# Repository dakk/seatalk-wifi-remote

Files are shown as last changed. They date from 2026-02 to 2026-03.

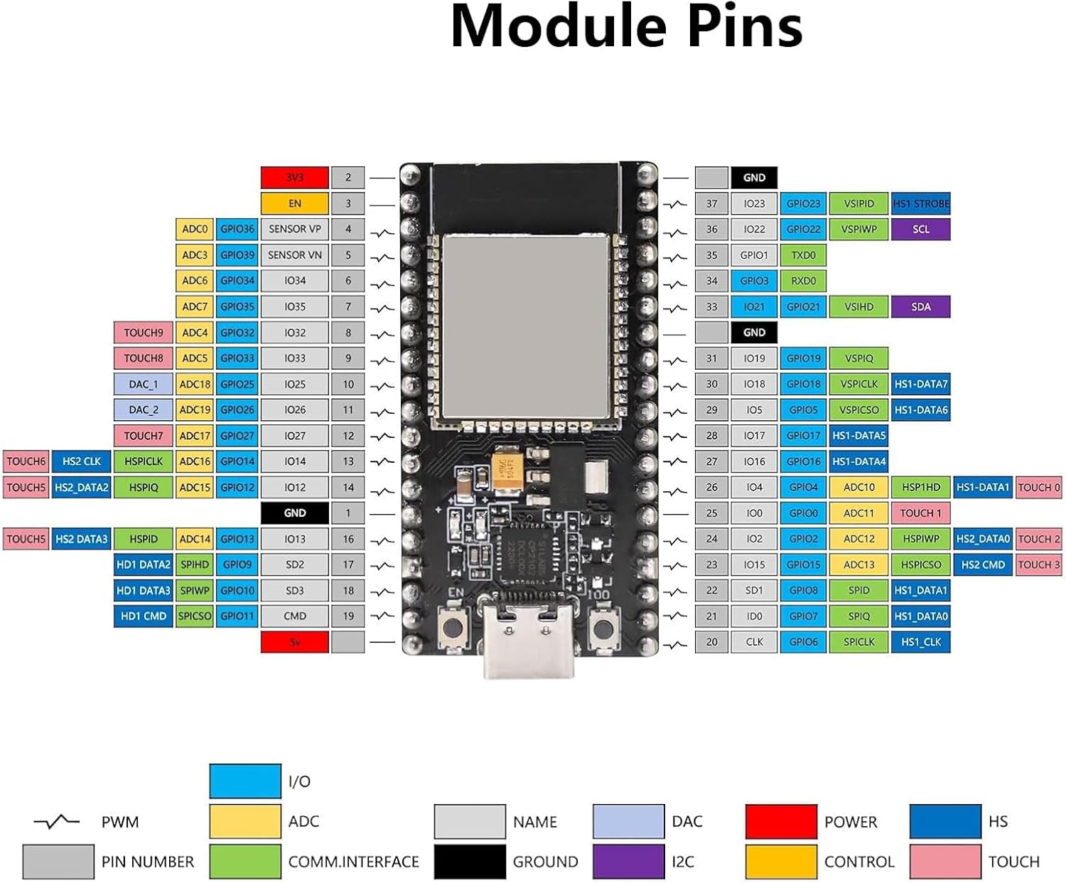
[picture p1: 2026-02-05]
media/esp32pinout.jpg

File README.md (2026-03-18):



# SeaTalk WiFi Remote

An ESP32-based wireless remote controller for marine autopilot systems using the SeaTalk protocol. Control your autopilot remotely over WiFi instead of using hardwired physical buttons.

## Features

- **6 programmable buttons** for autopilot control
- **WiFi UDP communication** to SeaTalk gateway
- **Deep sleep mode** for battery conservation
- **Auto-wake** on button press
- **LED status indicator** with visual feedback patterns
- **3D printable enclosure** (OpenSCAD parametric design)

## Button Functions

| Button | GPIO | Function |
|---|---|---|
| BTN1 | 32 | -1° heading |
| BTN2 | 33 | +1° heading |
| BTN3 | 25 | -10° heading |
| BTN4 | 26 | +10° heading |
| BTN5 | 27 | Auto/Standby toggle |
| BTN6 | 14 | Track mode |

## Hardware Requirements

- ESP32 development board
- 6x tactile push buttons
- LED + resistor (optional, GPIO 2)
- LiPo battery for portable operation
- USB-C charging circuit
- WiFi-to-SeaTalk gateway on your network

## Wiring

All buttons use internal pull-up resistors. Connect buttons between GPIO and GND.

```
ESP32 GPIO 32 ----[BTN1]---- GND
ESP32 GPIO 33 ----[BTN2]---- GND
ESP32 GPIO 25 ----[BTN3]---- GND
ESP32 GPIO 26 ----[BTN4]---- GND
ESP32 GPIO 27 ----[BTN5]---- GND
ESP32 GPIO 14 ----[BTN6]---- GND
ESP32 GPIO 2  ----[LED]--[R]---- GND
```

## Configuration

1. Copy the example configuration file:

```bash
cp seatalk-wifi-remote/conf_example.h seatalk-wifi-remote/conf.h
```

2. Edit `seatalk-wifi-remote/conf.h` with your WiFi credentials and gateway settings:

```cpp
#define WIFI_SSID "MyBoatWiFi"
#define WIFI_PASSWORD "my_secret_password"

#define SEATALK_GATEWAY_IP "192.168.1.100"  // SeaTalk gateway IP
#define SEATALK_GATEWAY_PORT 4001           // SeaTalk gateway port
```

> **Note:** `conf.h` is gitignored to prevent committing your credentials.

## Building

### Prerequisites

- [Arduino CLI](https://arduino.github.io/arduino-cli/)
- ESP32 Arduino core

### Install ESP32 Core

```bash
cd seatalk-wifi-remote
make install-core
```

### Build and Upload

```bash
make build          # Compile only
make upload         # Build and upload
make monitor        # Open serial monitor
make upload-monitor # Upload and open monitor
```

## Power Management

- **Enter sleep**: Hold BTN1 + BTN6 for 2 seconds
- **Wake up**: Press any button
- **Auto-sleep**: After 1 minute of inactivity (configurable)

### LED Patterns

| Pattern | Meaning |
|---|---|
| 3 blinks | Startup complete |
| Single flash | Command sent |
| 10 rapid blinks | WiFi connection error |
| 5 blinks | Entering sleep mode |

## 3D Printed Enclosure

Multiple enclosure versions are available in the `enclosure/` directory:

### Version 3 (Recommended)

Located in `enclosure/v3/` - waterproof custom design with TPU button mask and back gasket.

**Dimensions:** 82mm × 102mm × 35mm (external)

```bash
cd enclosure/v3
make           # Generate all STL files
```

### Version 2

Located in `enclosure/v2/` - YAPP-based design with 20mm internal clearance for ESP32 and battery.

**Dimensions:** 78mm × 98mm × 35mm (external)

```bash
cd enclosure/v2
make           # Generate all STL files
```

### Version 1 (Compact)

Located in `enclosure/v1-mini/` - compact nke-style remote design.

**Dimensions:** 78mm × 58mm × 23mm (external)

## SeaTalk Protocol

The remote sends SeaTalk Datagram 86 (Autopilot Remote Keystroke) commands:

| Key Code | Command |
|---|---|
| 0x05 | -1° |
| 0x06 | +1° |
| 0x07 | -10° |
| 0x08 | +10° |
| 0x01 | Auto |
| 0x02 | Standby |
| 0x03 | Track |

## License

MIT License

## Acknowledgments

- [YAPP Box Generator](https://github.com/mrWheel/YAPP_Box) for parametric enclosure design
- SeaTalk protocol documentation from the marine open-source community

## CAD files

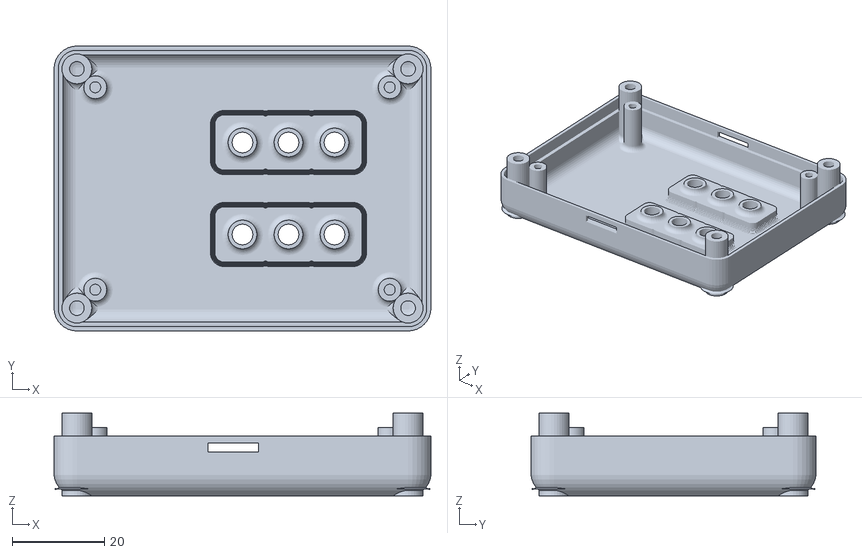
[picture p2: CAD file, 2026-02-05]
enclosure/v1-mini/auto_top.stl
82.0 x 62.0 x 18.0

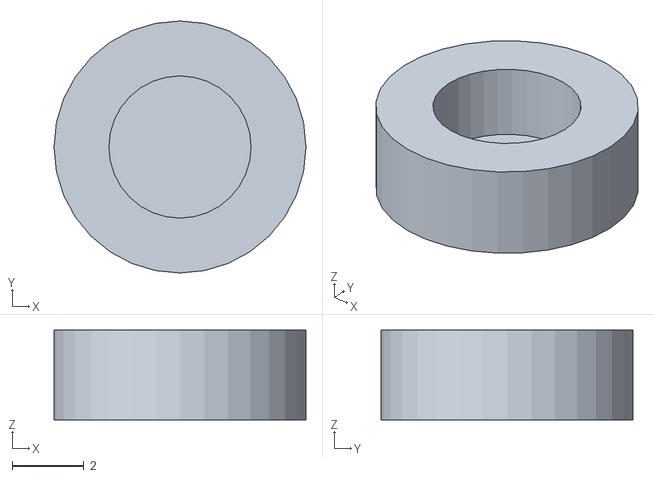
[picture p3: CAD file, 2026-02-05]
enclosure/v1-mini/auto_button_b.stl
7.00 x 7.00 x 2.50

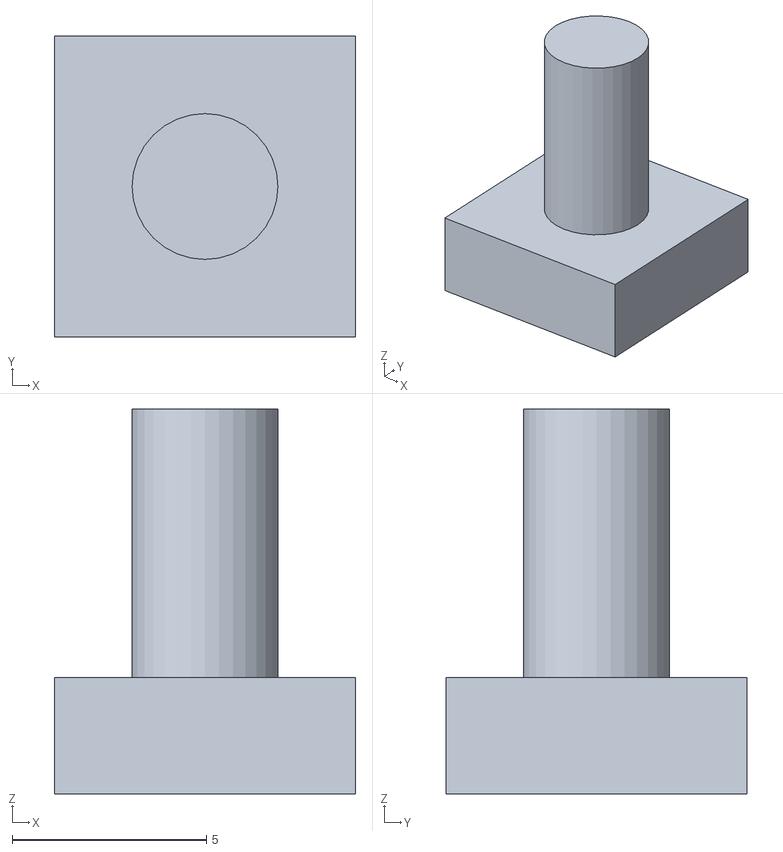
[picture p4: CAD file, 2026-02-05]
enclosure/v1-mini/auto_button_a.stl
7.75 x 7.75 x 9.90

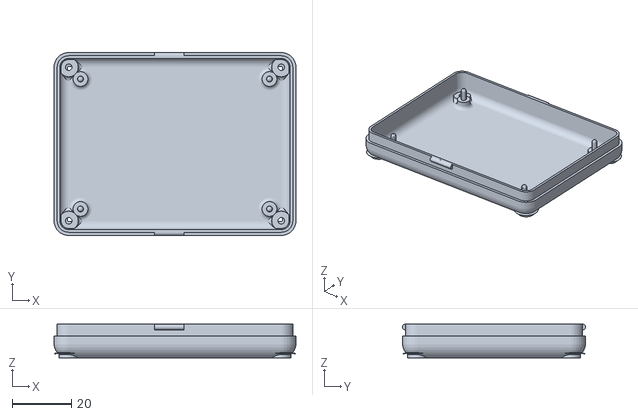
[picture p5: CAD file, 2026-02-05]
enclosure/v1-mini/auto_bottom.stl
82.0 x 62.0 x 11.5

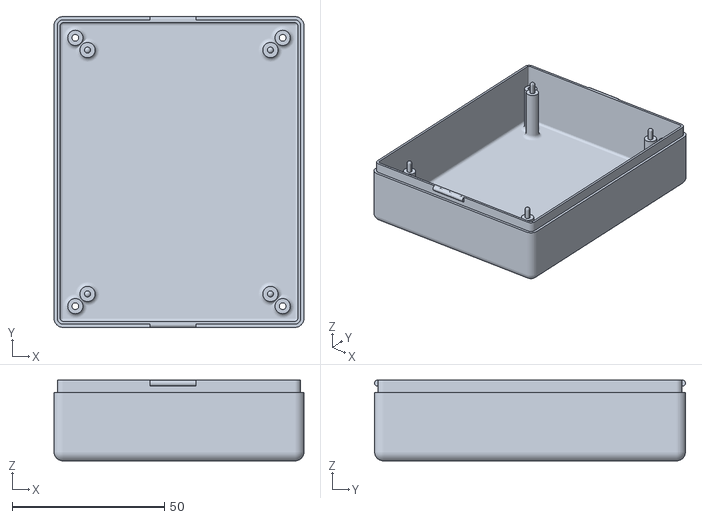
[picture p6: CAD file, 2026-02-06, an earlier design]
enclosure/v2/stl/base.stl
82.0 x 102.0 x 26.5

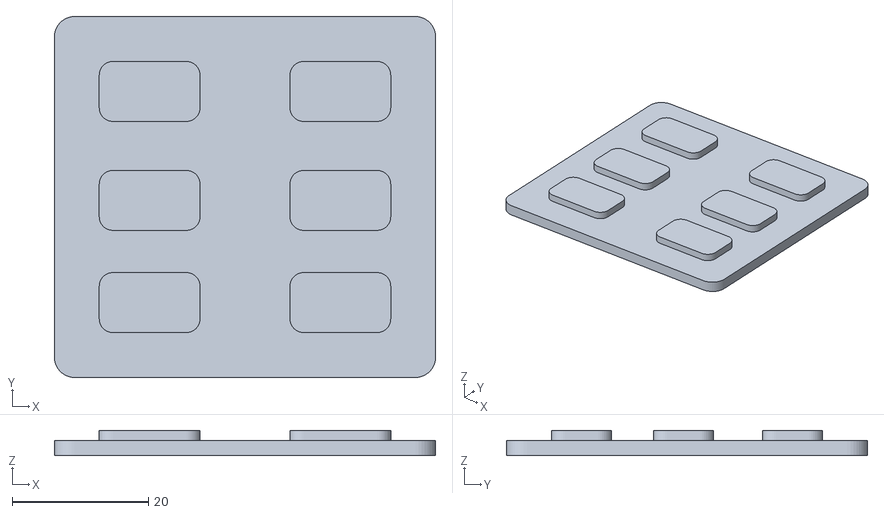
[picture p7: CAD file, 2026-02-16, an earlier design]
enclosure/v3/stl/tpu_mask.stl
56.0 x 53.0 x 3.70

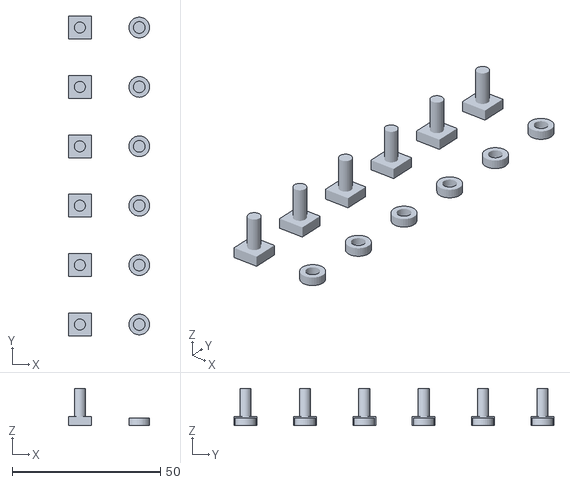
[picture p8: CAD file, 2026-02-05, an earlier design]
enclosure/v2/stl/extenders.stl
27.4 x 107.8 x 12.5

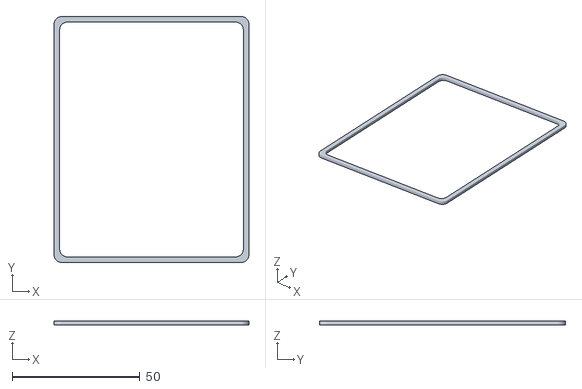
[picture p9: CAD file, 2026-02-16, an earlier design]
enclosure/v3/stl/back_gasket.stl
76.2 x 96.2 x 1.40

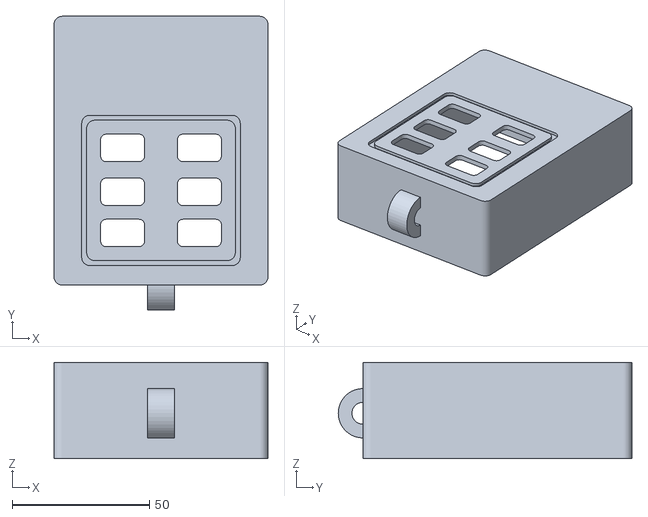
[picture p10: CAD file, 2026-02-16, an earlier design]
enclosure/v3/stl/enclosure.stl
78.0 x 107.0 x 35.0

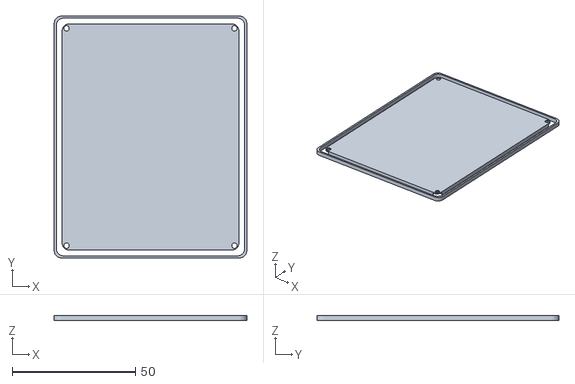
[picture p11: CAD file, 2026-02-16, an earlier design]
enclosure/v3/stl/back_cover.stl
78.0 x 98.0 x 2.00

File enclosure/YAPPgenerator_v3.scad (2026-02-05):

/*
***************************************************************************  
**  Yet Another Parameterised Projectbox generator
**
*/

Version="v3.1.2 (2024-04-12)";

/*
**
**  Copyright (c) 2021, 2022, 2023, 2024 Willem Aandewiel
**
**  With help from:
**   - Keith Hadley (parameterized label depth)
**   - Oliver Grafe (connectorsPCB)
**   - Juan Jose Chong (dynamic standoff flange)
**   - Dan Drum (cleanup code)
**   - Dave Rosenhauer (fillets and a lot more)
**
**
**  for many or complex cutouts you might need to adjust
**  the number of elements:
**
**      Preferences->Advanced->Turn off rendering at 250000 elements
**                                                  ^^^^^^
**
**  TERMS OF USE: MIT License. See base offile.
***************************************************************************      
*/

// If set to true will generate the sample box at every save
debug = false;
printMessages = debug;

//---------------------------------------------------------
// This design is parameterized based on the size of a PCB.
//---------------------------------------------------------
// Note: length/lengte refers to X axis, 
//       width/breedte to Y, 
//       height/hoogte to Z

/*
      padding-back|<------pcb length --->|<padding-front
                            RIGHT
        0    X-axis ---> 
        +----------------------------------------+   ---
        |                                        |    ^
        |                                        |   padding-right 
      Y |                                        |    v
      | |    -5,y +----------------------+       |   ---              
 B    a |         | 0,y              x,y |       |     ^              F
 A    x |         |                      |       |     |              R
 C    i |         |                      |       |     | pcb width    O
 K    s |         |                      |       |     |              N
        |         | 0,0              x,0 |       |     v              T
      ^ |    -5,0 +----------------------+       |   ---
      | |                                        |    padding-left
      0 +----------------------------------------+   ---
        0    X-as --->
                          LEFT
*/

//-- which part(s) do you want to print?
printBaseShell        = true;
printLidShell         = true;
printSwitchExtenders  = true;
printDisplayClips     = true;
shiftLid              = 10;  // Set the distance between the lid and base when rendered or previewed side by side
                            
//-- padding between pcb and inside wall
paddingFront        = 1;
paddingBack         = 1;
paddingRight        = 1;
paddingLeft         = 1;

// ********************************************************************
// The Following will be used as the first element in the pbc array

//Defined here so you can define the "Main" PCB using these if wanted
pcbLength           = 120; // front to back (X axis)
pcbWidth            = 50; // side to side (Y axis)
pcbThickness        = 1.6;
standoffHeight      = 1.0;  //-- How much the PCB needs to be raised from the base to leave room for solderings 
standoffDiameter    = 7;
standoffPinDiameter = 2.4;
standoffHoleSlack   = 0.4;

//===================================================================
// *** PCBs ***
// Printed Circuit Boards
//-------------------------------------------------------------------
//  Default origin =  yappCoordPCB : yappCoordBoxInside[0,0,0]
//
//  Parameters:
//   Required:
//    p(0) = name
//    p(1) = length
//    p(2) = width
//    p(3) = posx
//    p(4) = posy
//    p(5) = Thickness
//    p(6) = standoff_Height
//    p(7) = standoff_Diameter
//    p(8) = standoff_PinDiameter
//   Optional:
//    p(9) = standoff_HoleSlack (default to 0.4)

//The following can be used to get PCB values. If "PCB Name" is omitted then "Main" is used
//  pcbLength           --> pcbLength("PCB Name")
//  pcbWidth            --> pcbWidth("PCB Name")
//  pcbThickness        --> pcbThickness("PCB Name") 
//  standoffHeight      --> standoffHeight("PCB Name") 
//  standoffDiameter    --> standoffDiameter("PCB Name") 
//  standoffPinDiameter --> standoffPinDiameter("PCB Name") 
//  standoffHoleSlack   --> standoffHoleSlack("PCB Name") 

pcb = 
[
  //-- Default Main PCB - DO NOT REMOVE the "Main" line.
  ["Main",              pcbLength,pcbWidth,    0,0,    pcbThickness,  standoffHeight, standoffDiameter, standoffPinDiameter, standoffHoleSlack]
];

//-------------------------------------------------------------------

//-- Edit these parameters for your own box dimensions
wallThickness       = 2.0;
basePlaneThickness  = 1.5;
lidPlaneThickness   = 1.5;

//-- Total height of box = lidPlaneThickness 
//                       + lidWallHeight 
//                       + baseWallHeight 
//                       + basePlaneThickness
//-- space between pcb and lidPlane :=
//--      (bottonWallHeight+lidWallHeight) - (standoff_Height+pcb_Thickness)
baseWallHeight      = 10;
lidWallHeight       = 10;

//-- ridge where base and lid off box can overlap
//-- Make sure this isn't less than lidWallHeight 
//     or 1.8x wallThickness if using snaps
ridgeHeight         = 5.0;
ridgeSlack          = 0.3;

//-- Radius of the shell corners
roundRadius         = wallThickness + 1;

//---------------------------
//--     MISC Options     --
//---------------------------

//-- Cone aperture in degrees for countersunk-head screws
countersinkAngle = 90;          //-- metric: 90

// Set the layer height of your printer
printerLayerHeight  = 0.2;

// Set the ratio between the wall thickness and the ridge height. 
//    Recommended to be left at 1.8 but for strong snaps.
wallToRidgeRatio = 1.8;

//---------------------------
//--     C O N T R O L     --
//---------------------------
// -- Render --
renderQuality             = 8;          //-> from 1 to 32, Default = 8

// --Preview --
previewQuality            = 5;          //-> from 1 to 32, Default = 5
showSideBySide            = true;       //-> Default = true
onLidGap                  = 0;  // tip don't override to animate the lid opening
//onLidGap                  = ((ridgeHeight) - (ridgeHeight * abs(($t-0.5)*2)))*2;  // tip don't override to animate the lid opening/closing
colorLid                  = "YellowGreen";   
alphaLid                  = 1;
colorBase                 = "BurlyWood";
alphaBase                 = 1;
hideLidWalls              = false;      //-> Remove the walls from the lid : only if preview and showSideBySide=true 
hideBaseWalls             = false;      //-> Remove the walls from the base : only if preview and showSideBySide=true  
showOrientation           = true;       //-> Show the Front/Back/Left/Right labels : only in preview
showPCB                   = false;      //-> Show the PCB in red : only in preview 
showSwitches              = false;      //-> Show the switches (for pushbuttons) : only in preview 
showButtonsDepressed      = false;      //-> Should the buttons in the Lid On view be in the pressed position
showOriginCoordBox        = false;      //-> Shows red bars representing the origin for yappCoordBox : only in preview 
showOriginCoordBoxInside  = false;      //-> Shows blue bars representing the origin for yappCoordBoxInside : only in preview 
showOriginCoordPCB        = false;      //-> Shows blue bars representing the origin for yappCoordBoxInside : only in preview 
showMarkersPCB            = false;      //-> Shows black bars corners of the PCB : only in preview 
showMarkersCenter         = false;      //-> Shows magenta bars along the centers of all faces  
inspectX                  = 0;          //-> 0=none (>0 from Back)
inspectY                  = 0;          //-> 0=none (>0 from Right)
inspectZ                  = 0;          //-> 0=none (>0 from Bottom)
inspectXfromBack          = true;       //-> View from the inspection cut foreward
inspectYfromLeft          = true;       //-> View from the inspection cut to the right
inspectZfromBottom        = true;       //-> View from the inspection cut up
//---------------------------
//--     C O N T R O L     --
//---------------------------

// ******************************
//  REMOVE BELOW FROM TEMPLATE

// Set the glogal for the quality
facetCount = $preview ? previewQuality*4 : renderQuality*4;

//-- better leave these ----------
buttonWall          = 2.0;
buttonPlateThickness= 2.5;
buttonSlack         = 0.25;

//-- constants, do not change (shifted to large negative values so another element in the 
//-- array won't match

// Define some alternates to undef
yappDefault             = undef;
default                 = undef;

// Shapes
yappRectangle           = -30000;
yappCircle              = -30001;
yappPolygon             = -30002;
yappRoundedRect         = -30003;
yappCircleWithFlats     = -30004;
yappCircleWithKey       = -30005;
yappRing                = -30006;
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

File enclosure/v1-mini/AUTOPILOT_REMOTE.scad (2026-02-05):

//-----------------------------------------------------------------------
// ESP32 Sailing Autopilot Remote - nke style
// Based on YAPP Box Generator v3
//-----------------------------------------------------------------------
include <../Enclosures/YAPP_Box/YAPPgenerator_v3.scad>

//-- which part(s) do you want to print?
printBaseShell        = true;
printLidShell         = true;
printSwitchExtenders  = true;

// PCB dimensions - adjust to your ESP32 board
pcbLength           = 70;    // X axis (front to back)
pcbWidth            = 50;    // Y axis (side to side)
pcbThickness        = 1.6;
standoffHeight      = 3.0;   // space below PCB for soldering/battery
standoffDiameter    = 5;
standoffPinDiameter = 2.0;
standoffHoleSlack   = 0.4;

pcb = 
[
  ["Main", pcbLength, pcbWidth, 0, 0, pcbThickness, standoffHeight, 
   standoffDiameter, standoffPinDiameter, standoffHoleSlack]
];

//-- padding between PCB and inside wall
paddingFront  = 4;
paddingBack   = 4;
paddingRight  = 4;
paddingLeft   = 4;

//-- wall dimensions
wallThickness       = 2.0;
basePlaneThickness  = 1.5;
lidPlaneThickness   = 1.5;

//-- Total height ~23mm (nke remote style)
baseWallHeight  = 10;
lidWallHeight   = 8;

//-- ridge for lid/base overlap (sealing area)
ridgeHeight  = 4.0;
ridgeSlack   = 0.2;
roundRadius  = 5.0;   // rounded corners

boxType = 0;  // all edges rounded

printerLayerHeight = 0.2;

//-- Preview settings
renderQuality    = 8;
previewQuality   = 5;
showSideBySide   = true;
colorLid         = "DarkSlateGray";
colorBase        = "SlateGray";
showPCB          = true;
showSwitches     = true;

//===================================================================
// *** PCB Supports - mounting posts for ESP32 ***
//-------------------------------------------------------------------
pcbStands = 
[
  // 4 corner standoffs (adjust to your ESP32 mounting holes)
  [3,  3,  standoffHeight, -1, standoffDiameter, standoffPinDiameter],
  [3,  pcbWidth-3],
  [pcbLength-3, 3],
  [pcbLength-3, pcbWidth-3]
];

//===================================================================
// *** Cutouts - FIXED FORMAT ***
//-------------------------------------------------------------------
cutoutsLid = 
[
  // 6 button holes: 10mm diameter circles, 2x3 grid centered on lid
  // Format: [x, y, diameter, diameter, yappCircle]
  // Row 1 (top)
  [35, 15, 10, 10, yappCircle],
  [35, 35, 10, 10, yappCircle],
  // Row 2 (middle)  
  [45, 15, 10, 10, yappCircle],
  [45, 35, 10, 10, yappCircle],
  // Row 3 (bottom)
  [55, 15, 10, 10, yappCircle],
  [55, 35, 10, 10, yappCircle]
];

cutoutsBase = [];

// USB-C charging port on front face
cutoutsFront = 
[
  // USB-C: 9mm wide x 3.5mm tall, centered vertically
  [9, 32, 9, 3.5, yappRoundedRect]
];

cutoutsBack   = [];
cutoutsLeft   = [];
cutoutsRight  = [];

//===================================================================
// *** Push Buttons - printed extenders for tactile switches ***
//-------------------------------------------------------------------
pushButtons = 
[
  // Match cutouts exactly - adjust switchHeight to your tact switches
  [35, 15, 8, 8, 2, 1.5, 6.0, 0.5, 4, standoffHeight + pcbThickness],
  [35, 35, 8, 8, 2, 1.5, 6.0, 0.5, 4, standoffHeight + pcbThickness],
  [45, 15, 8, 8, 2, 1.5, 6.0, 0.5, 4, standoffHeight + pcbThickness],
  [45, 35, 8, 8, 2, 1.5, 6.0, 0.5, 4, standoffHeight + pcbThickness],
  [55, 15, 8, 8, 2, 1.5, 6.0, 0.5, 4, standoffHeight + pcbThickness],
  [55, 35, 8, 8, 2, 1.5, 6.0, 0.5, 4, standoffHeight + pcbThickness]
];

//===================================================================
// *** Snap Joins - clips to hold lid and base together ***
//-------------------------------------------------------------------
snapJoins = 
[
  [(pcbLength + paddingFront + paddingBack)/2, 10, yappLeft, yappRight, yappCenter]
];

//===================================================================
// *** Labels - embossed text ***
//-------------------------------------------------------------------
labelsPlane = 
[
  // Example button labels
  // [45, 15+12, 0, 0.4, yappLid, "Liberation Sans:style=Bold", 4, "AUTO"],
  // [45, 35-12, 0, 0.4, yappLid, "Liberation Sans:style=Bold", 4, "STBY"],
  // [35, 25, 0, 0.4, yappLid, "Liberation Sans", 3, "+1"],
  // [55, 25, 0, 0.4, yappLid, "Liberation Sans", 3, "-1"]
];

//===================================================================
// *** Connectors - screw posts for secure closure ***
//-------------------------------------------------------------------
connectors = 
[
  // 4 corner M2 screw posts
  [5, 5, standoffHeight, 2.2, 4.5, 2.2, 4, yappAllCorners, yappCoordBox],
];

boxMounts     = [];
lightTubes    = [];
ridgeExtLeft  = [];
ridgeExtRight = [];
ridgeExtFront = [];
ridgeExtBack  = [];
displayMounts = [];

//---- Generate the box ----
YAPPgenerate();

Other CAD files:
enclosure/v2/AUTOPILOT_REMOTE.scad
enclosure/v3/v3.scad

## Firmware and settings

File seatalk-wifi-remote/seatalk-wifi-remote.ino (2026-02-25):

/*
 * SeaTalk WiFi Remote Controller
 * ESP32-based remote with 6 buttons for autopilot control
 *
 * Features:
 * - WiFi connectivity to SeaTalk gateway
 * - 6 configurable buttons for autopilot commands
 * - Deep sleep mode (BTN1 + BTN6 to enter sleep)
 * - Wake from sleep by pressing BTN1 (Auto)
 */

#include <WiFi.h>
#include <WiFiUdp.h>
#include <esp_sleep.h>
#include <driver/rtc_io.h>

// ============== CONFIGURATION ==============

#include "conf.h"

// Button GPIO pins (choose RTC-capable GPIOs for wake-up support)
// RTC GPIOs on ESP32: 0, 2, 4, 12-15, 25-27, 32-39
#define BTN1_PIN  32  // -1 degree
#define BTN2_PIN  33  // +1 degree
#define BTN3_PIN  25  // -10 degrees
#define BTN4_PIN  26  // +10 degrees
#define BTN5_PIN  27  // Auto/Standby toggle
#define BTN6_PIN  14  // Track mode

// LED indicator (optional)
#define LED_PIN   2

// Button debounce time in milliseconds
#define DEBOUNCE_MS 50

// Sleep mode key combination hold time (milliseconds)
#define SLEEP_COMBO_HOLD_MS 2000

// WiFi connection timeout (milliseconds)
#define WIFI_TIMEOUT_MS 10000

// ============== SEATALK COMMANDS ==============
// SeaTalk autopilot remote keystroke commands (Datagram 86)
// Format: 86 X1 YY - where X1 = key code, YY = 0x00

// Keystroke codes for autopilot
const uint8_t ST_KEY_MINUS_1    = 0x05;  // -1 degree
const uint8_t ST_KEY_PLUS_1     = 0x06;  // +1 degree
const uint8_t ST_KEY_MINUS_10   = 0x07;  // -10 degrees
const uint8_t ST_KEY_PLUS_10    = 0x08;  // +10 degrees
const uint8_t ST_KEY_AUTO       = 0x01;  // Auto mode
const uint8_t ST_KEY_STANDBY    = 0x02;  // Standby mode

// ============== GLOBAL VARIABLES ==============

WiFiUDP udp;

// Button state tracking
struct Button {
  uint8_t pin;
  uint8_t command;
  bool lastState;
  bool currentState;
  unsigned long lastDebounceTime;
  bool pressed;
};

Button buttons[6] = {
  {BTN1_PIN, ST_KEY_AUTO,  true, true, 0, false},
  {BTN2_PIN, ST_KEY_MINUS_10,   true, true, 0, false},
  {BTN3_PIN, ST_KEY_MINUS_1, true, true, 0, false},
  {BTN4_PIN, ST_KEY_PLUS_1,  true, true, 0, false},
  {BTN5_PIN, ST_KEY_PLUS_10,     true, true, 0, false},  // Toggle auto/standby
  {BTN6_PIN, ST_KEY_STANDBY,  true, true, 0, false}
};

unsigned long sleepComboStartTime = 0;
bool sleepComboActive = false;
unsigned long lastActivityTime = 0;  // Track last button activity for auto-sleep
int wifiFailCount = 0;  // Track consecutive WiFi connection failures

// ============== FUNCTION DECLARATIONS ==============

void setupButtons();
void setupWiFi();
void updateButtons();
uint8_t nmeaChecksum(const char* sentence);
void sendSeaTalkCommand(uint8_t keyCode);
void checkSleepCombo();
void enterDeepSleep();
void blinkLED(int times, int delayMs);
void printWakeupReason();

// ============== SETUP ==============

void setup() {
  Serial.begin(115200);
  delay(100);

  Serial.println("\n\n=================================");
  Serial.println("SeaTalk WiFi Remote Controller");
  Serial.println("=================================\n");

  // Print wake-up reason
  printWakeupReason();

  // Initialize LED
  pinMode(LED_PIN, OUTPUT);
  digitalWrite(LED_PIN, LOW);

  // Initialize buttons
  setupButtons();

  #ifdef DEBUG_MODE
    Serial.println("*** DEBUG MODE ENABLED ***");
    Serial.println("WiFi and SeaTalk are disabled.");
    Serial.println("Press any button to test. LED blinks = button number.\n");
    blinkLED(10, 50);
  #else
    // Connect to WiFi
    setupWiFi();
  #endif

  // Indicate ready
  blinkLED(3, 100);

  // Initialize activity timer
  lastActivityTime = millis();

  Serial.println("\nRemote ready!");
  Serial.println("- Press BTN1+BTN6 for 2 seconds to enter sleep mode");
  Serial.printf("- Auto-sleep after %d minutes of inactivity\n", INACTIVITY_TIMEOUT_MIN);
  Serial.println("- Press BTN1 (Auto) to wake from sleep\n");
}

// ============== MAIN LOOP ==============

void loop() {
  // Check WiFi connection
  #ifndef DEBUG_MODE
    if (WiFi.status() != WL_CONNECTED) {
      Serial.println("WiFi disconnected, reconnecting...");
      setupWiFi();
    }
  #endif

  // Update button states
  updateButtons();

  // Check for sleep mode combination (BTN1 + BTN6)
  checkSleepCombo();

  // Process button presses
  for (int i = 0; i < 6; i++) {
    if (buttons[i].pressed) {
      buttons[i].pressed = false;
      lastActivityTime = millis();  // Reset inactivity timer

      sendSeaTalkCommand(buttons[i].command);
    }
  }

  // Check for inactivity timeout
  if ((millis() - lastActivityTime) >= (unsigned long)INACTIVITY_TIMEOUT_MIN * 60000UL) {
    Serial.println("Inactivity timeout reached, entering sleep...");
    enterDeepSleep();
  }

  delay(10);
}

// ============== BUTTON FUNCTIONS ==============

void setupButtons() {
  for (int i = 0; i < 6; i++) {
    pinMode(buttons[i].pin, INPUT_PULLUP);
    buttons[i].lastState = digitalRead(buttons[i].pin);
    buttons[i].currentState = buttons[i].lastState;
  }
  Serial.println("Buttons initialized");
}

void updateButtons() {
  for (int i = 0; i < 6; i++) {
    bool reading = digitalRead(buttons[i].pin);

    // Check if button state changed
    if (reading != buttons[i].lastState) {
      buttons[i].lastDebounceTime = millis();
    }

    // If debounce time passed, update state
    if ((millis() - buttons[i].lastDebounceTime) > DEBOUNCE_MS) {
      if (reading != buttons[i].currentState) {
        buttons[i].currentState = reading;

        // Button pressed (LOW because of INPUT_PULLUP)
        if (buttons[i].currentState == LOW) {
          buttons[i].pressed = true;
          Serial.printf("Button %d pressed\n", i + 1);
        }
      }
    }

    buttons[i].lastState = reading;
  }
}

// ============== SLEEP FUNCTIONS ==============

void checkSleepCombo() {
  // Check if BTN1 (index 0) and BTN6 (index 5) are both pressed
  bool btn1Pressed = (buttons[0].currentState == LOW);
  bool btn6Pressed = (buttons[5].currentState == LOW);

  if (btn1Pressed && btn6Pressed) {
    if (!sleepComboActive) {
      sleepComboActive = true;
      sleepComboStartTime = millis();
      Serial.println("Sleep combo detected, hold for 2 seconds...");
    } else if ((millis() - sleepComboStartTime) >= SLEEP_COMBO_HOLD_MS) {
      Serial.println("Entering deep sleep...");
      enterDeepSleep();
    }
  } else {
    if (sleepComboActive) {
      Serial.println("Sleep combo released");
    }
    sleepComboActive = false;
  }
}

void enterDeepSleep() {
  // Indicate entering sleep
  blinkLED(5, 200);

  // Disconnect WiFi to save power
  WiFi.disconnect(true);
  WiFi.mode(WIFI_OFF);

  // Configure wake-up source using EXT0 (single pin, supports LOW level trigger)
  // Note: Original ESP32 EXT1 only supports ALL_LOW or ANY_HIGH, neither works
  // for waking on a single active-low button press. EXT0 supports one pin with LOW trigger.
  // To wake from any button, add Schottky diodes from each button to a common wake pin.
  rtc_gpio_pullup_en((gpio_num_t)BTN1_PIN);
  rtc_gpio_pulldown_dis((gpio_num_t)BTN1_PIN);
  esp_sleep_enable_ext0_wakeup((gpio_num_t)BTN1_PIN, LOW);

  Serial.println("Going to sleep now. Press BTN1 (Auto) to wake up.");
  Serial.flush();

  // Enter deep sleep
  esp_deep_sleep_start();
}

void printWakeupReason() {
  esp_sleep_wakeup_cause_t wakeup_reason = esp_sleep_get_wakeup_cause();

  switch (wakeup_reason) {
    case ESP_SLEEP_WAKEUP_EXT0:
      Serial.println("Wakeup caused by external signal using RTC_IO");
      break;
    case ESP_SLEEP_WAKEUP_EXT1:
      Serial.println("Wakeup caused by external signal using RTC_CNTL");
      break;
    case ESP_SLEEP_WAKEUP_TIMER:
      Serial.println("Wakeup caused by timer");
      break;
    case ESP_SLEEP_WAKEUP_TOUCHPAD:
      Serial.println("Wakeup caused by touchpad");
      break;
    case ESP_SLEEP_WAKEUP_ULP:
      Serial.println("Wakeup caused by ULP program");
      break;
    default:
      Serial.printf("Wakeup was not caused by deep sleep: %d\n", wakeup_reason);
      break;
  }
}

// ============== WIFI FUNCTIONS ==============

void setupWiFi() {
  Serial.printf("Connecting to WiFi: %s\n", WIFI_SSID);

  WiFi.mode(WIFI_STA);
  WiFi.begin(WIFI_SSID, WIFI_PASSWORD);

  unsigned long startTime = millis();
  while (WiFi.status() != WL_CONNECTED) {
    if (millis() - startTime > WIFI_TIMEOUT_MS) {
      wifiFailCount++;
      Serial.printf("\nWiFi connection timeout! (attempt %d/4)\n", wifiFailCount);
      blinkLED(10, 50);
      if (wifiFailCount >= 4) {
        Serial.println("4 failed WiFi attempts, entering standby...");
        enterDeepSleep();
      }
      return;
    }
    delay(500);
    Serial.print(".");
    digitalWrite(LED_PIN, !digitalRead(LED_PIN));
  }

  wifiFailCount = 0;
  digitalWrite(LED_PIN, HIGH);
  Serial.println("\nWiFi connected!");
  Serial.printf("IP address: %s\n", WiFi.localIP().toString().c_str());

  // Initialize UDP
  udp.begin(SEATALK_GATEWAY_PORT);
}

// ============== SEATALK FUNCTIONS ==============

uint8_t nmeaChecksum(const char* sentence) {
  uint8_t cs = 0;
  // XOR all characters between '$' and '*'
  for (int i = 1; sentence[i] && sentence[i] != '*'; i++) {
    cs ^= sentence[i];
  }
  return cs;
}

void sendSeaTalkCommand(uint8_t keyCode) {
  // SeaTalk Datagram 86: Autopilot Remote Keystroke
  // Format: $STALK,86,21,code1,code2*CS
  // code1 = keyCode, code2 = 0xFF - keyCode

  uint8_t code2 = 0xFF - keyCode;

  // Build NMEA sentence without checksum
  char sentence[40];
  snprintf(sentence, sizeof(sentence), "$STALK,86,21,%02X,%02X*", keyCode, code2);

  // Compute and append checksum
  uint8_t cs = nmeaChecksum(sentence);
  char msg[48];
  snprintf(msg, sizeof(msg), "$STALK,86,21,%02X,%02X*%02X\r\n", keyCode, code2, cs);

  #ifdef DEBUG_MODE
    Serial.printf("[DEBUG] Would send: %s", msg);
    blinkLED(3, 100);
    return;
  #endif

  // Send via UDP to SeaTalk gateway
  udp.beginPacket(SEATALK_GATEWAY_IP, SEATALK_GATEWAY_PORT);
  udp.print(msg);
  udp.endPacket();

  Serial.printf("Sent: %s", msg);

  // Brief LED flash to indicate transmission
  digitalWrite(LED_PIN, LOW);
  delay(50);
  digitalWrite(LED_PIN, HIGH);
}

// ============== UTILITY FUNCTIONS ==============

void blinkLED(int times, int delayMs) {
  for (int i = 0; i < times; i++) {
    digitalWrite(LED_PIN, HIGH);
    delay(delayMs);
    digitalWrite(LED_PIN, LOW);
    delay(delayMs);
  }
}

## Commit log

2026-02-05 update box
    [AUTOPILOT_REMOTE.scad, extenders.stl]
2026-02-06 update enclosure
    [AUTOPILOT_REMOTE.scad, base.stl]
2026-02-11 enclosure v3
    [back_cover.stl, enclosure.stl, tpu_mask.stl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]
2026-02-12 enclosure v3 update
    [back_cover.stl, enclosure.stl, tpu_mask.stl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]
2026-02-15 fix sleep wake up
    [seatalk-wifi-remote.ino]
2026-02-15 update enclosure for battery holder
    [back_cover.stl, enclosure.stl, tpu_mask.stl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]
2026-02-16 add back gasket for waterproofing
    [back_cover.stl, back_gasket.stl, enclosure.stl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]
2026-02-25 update button mapping. add max retry for wifi connection

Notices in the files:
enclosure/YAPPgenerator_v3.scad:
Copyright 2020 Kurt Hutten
